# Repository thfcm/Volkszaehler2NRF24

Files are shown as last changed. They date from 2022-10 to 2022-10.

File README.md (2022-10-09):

# Volkszaehler2NRF24
A Battery powered Electric-Meter reader that sends data using nRF24 wireless.<br/>
This is based on the works of https://www.volkszaehler.org .
<br/>
<br/>
## Introduction
I started this project because I want to measure my power consumption during the day and see how my tiny 300pW Solar Power Plant fits in.
Fortunately, the electric-meter is a digital one with an IR interface for consumer-use that sends out a bunch or information like the counter reading or the current power reading.
As I live for rent and there is no power plug nearby my electric-meter, I was forced to build something that can last for a long time on a Battery.
<br/><br/>
The Receiver is in my cellar room next to the room with the power meters where my tiny home-server is running.
The far-end of this power-meter reader is directly connected to the home server via USB and sends the received data via a serial interface, so you can access it using Node-Red or anything else.

## Content
This project includes 

* [IRReader_Transmitter](https://github.com/thfcm/Volkszaehler2NRF24/tree/main/IRReader_Transmitter) - the IR Reader/Transmitter that you want to put on your energy-meter
* [Receiver](https://github.com/thfcm/Volkszaehler2NRF24/tree/main/Receiver) - the Receiver that receives the information and sends it to a Serial Port using USB
* [eMH Simulator](https://github.com/thfcm/Volkszaehler2NRF24/tree/main/eMH%20Simulator) - an eMH energy-meter simulator so you can test your hardware without standing next to your energy-meter with a laptop and strange devices in your hand that may  make neighbors asking strange questions

## Schematic:



## Hardware needed
<br/>
I build my prototype using hardware that I had lying around: 
- an IR diode that matches the wavelength of the NMH smart-meter by chance (needs to be determined but most IR diodes should work)
- an Arduino Board using a 328p microcontroller. We are going to run that one consuming as few power as possible. It does not matter if you are using the 16MHz/5V or the 8MHz/3.3V Version as we are going to modify that board to waste as few power as possible. In my case I was modifying an *Pro Micro board (16MHz/5V)* to run on 4MHz and 3.3V using an external power regulator.
- an nRF24 Transceiver. I was using an nRF24L01+ as I planned to use the 250kBaud transfer rate in the hope to use even less power with that. You should do fine with an nRF24L01 (without the "+"), too. In that case, you'll need to modify some settings as the non-plus transceivers do not support 250kBaud (they 'only' do 1MBaud or 2MBaud).
Your Receiver should match the capabilities.
- A Low-Dropout power regulator that has a small power consumption by its own. I am using HT7333 , but you can use any other regulatorthat fits, too. It even might be good to only use 3.0Volt or less (as long as it fits the needs of the 328p@4MHz and the nRF24). You can also stick with the one that is integrated on your board as long as it is a 3.3V regualtor as the nRF24-board will be destroyed if you run ith with 5V.
- a Sincle Cell (1S) LiPo Battery or something similiar. Make sure you use a Battery with a protection cirquit as I didn't integrated any protection. I am using a 18650 Battery with 2600mAh capacity and an integrated protection cirquit. Make sure the final discharging voltage is high enough so your voltage regulator can provide the minimum volate to your board as long as possible. You may even get rid of the power regulator if you can make sure that the end-of-charge voltage does not exceed the maximum rating of your nRF24 module.
<br/><br/>

## Hardware modification
<br/>
I removed the power LED as well as the power regulator that was mounted on the board. We do not need the LED. It only consumes power.
I also removed the integrated power regulator as it is not the most efficient one. It was replaced by the already mentioned external HT7333. You may do fine to keep the integrated one, depending on how less power you really want to waste.
I stabilized the 3.3V rail with a 220uF/10V condensator. That is optional but may help in case the nRF Module induces some peaks.
<br/>
<br/>

## Low Power
<br/>
When running something on battery, you usually want it to run as long as possible without replacing the battery.
I had the goal to have the reader running at least 6 month and ended up with more than 12 month (in theory - that needs to be confirmed).
<br/><br/>
To do so, I chose an Arduino compatible board that does not have a lot external peripheral attached. The Pro Mini I am using does not even have an USB port as the common USB-to-Serial chips use a lot of power even if you don't need them.
I also removed the power-LED as well as the integraded power regulator.
<br/><br/>
To save even more power, I have the Atmega328p running at 4MHz and using 3.3V. The less volts, the less power it is consuming. You can also run it with 3.0 Volts or even less to save even more power. 
I disabled all the internal peripheral devices the Atmega has and that we do not need (like ADC, Brown.out.Detection and so on).
<br/><br/>
I got that information from http://www.gammon.com.au/power so all the credits for that goes there.
<br/><br/>
In addition to that, the nRF24L01+ is set to a sleep mode as long as we don't have anything to send.
Also the Atmega328p is sleeping for most of its time. At the moment, it will sleep for 16 Seconds, wakes up, waits for some Serial Data from the IR port and extracts the data we want. It then sends those 8 Bytes and goes back to sleep again immediantly.
<br/><br/>

## Range

You might want to know the range of that system. But range depends on so many factors, you can not really tell anything. You should test it under the conditions you have.
To extend the range a little bot, you can raise the transmit power, add some shielding to the receiver to block noise of have a look at [https://www.instructables.com/Enhanced-NRF24L01/](https://www.instructables.com/Enhanced-NRF24L01/).

## Used external Libraries
<br/>
For that project we are using the following libraries:

* [RF24 Library from https://nrf24.github.io/RF24/](https://nrf24.github.io/RF24/)

* [AltSoftSerial from https://www.pjrc.com/teensy/td_libs_AltSoftSerial.html](https://www.pjrc.com/teensy/td_libs_AltSoftSerial.html) as the regular SoftwareSerial was too slow

* [SML Parser from https://github.com/olliiiver/sml_parser](https://github.com/olliiiver/sml_parser) to parse the SML Data the electric-meter sends

<br/><br/>
## Example Images







## Discord Server
I have opened a Discord Server so you can ask questions and exchange information.
Please note that I have a real live, too. So I might not be able to answear within minutes or at all.

https://discord.gg/fCE7YD76QE

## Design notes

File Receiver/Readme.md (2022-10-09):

# Receiver
This is the Receiver of this project.

It will send the data received via the nRF24l01+ Module to a Computer using Serial (via USB).
This might be your Node-Red-Server RaspberryPi or anything else.

You can run this code either on a Wemos D1 Mini (compatible with many ESP8266 based Boards) or a Arduino Nano V3 (compatible with most Atmega 328p-based boards).
It is easy to adapt this code for any other board, too.



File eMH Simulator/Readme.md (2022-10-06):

## eMH Simulator

This little piece of code will simulate an eMH energy-meter and will send simulated data using an IR Diode.
This way you can test your Volkszaehler2NRF24 on your desk until everything works.
<br/>
This sketch uses a binary file from the [libsml library from https://github.com/olliiiver/sml_parser](https://github.com/olliiiver/sml_parser) that contains a telegram similar to an eMH meter will send out.
Note, that at least the Address of the *current power* might differ from the Address your energy-meter might use (I had that in my case).
<br/>                        
I used a Teensy 3.1 Board that I had laying around but any other board should work fine, too.
In case you are going to use another board, you might have to replace Hardware-Serial 1 with a Software-Serial.
This is, because the Teensy is cabable of more than one Serial Interface that is mapped in hardware.
In case the board you are using does not have more than one Hardware Serial interface, you can use SoftwareSerial instead.

(I know this is confusing and I will change code to use SoftwareSerial in the future so you do not have to change this point in code for yourself)

<br/>                                 
Simply solder an IR TX Diode between 3.3V and your TX Pin. Depending on the Diode you are using, you should install the matching current limiting resistor.

Example:<br/>

<br/><br/>
You can check if the Simulator is sending data using your Smartphones Camera. <br/>
Most of them are capable of "seeing" infrared light (which looks like a purple pale light):<br/>


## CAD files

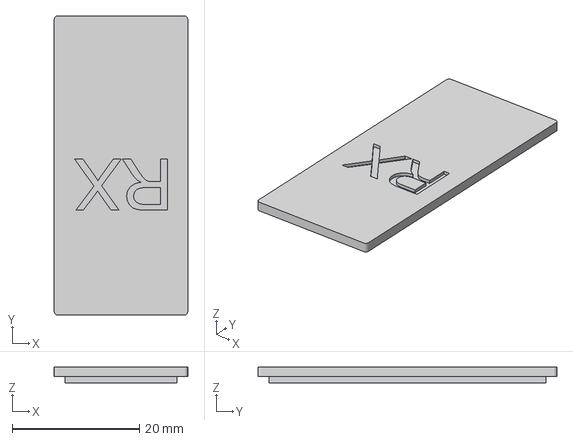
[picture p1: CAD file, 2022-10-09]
Receiver/3DprintCases/NanoProCase/lid.3mf
21.0 x 47.0 x 2.50 mm

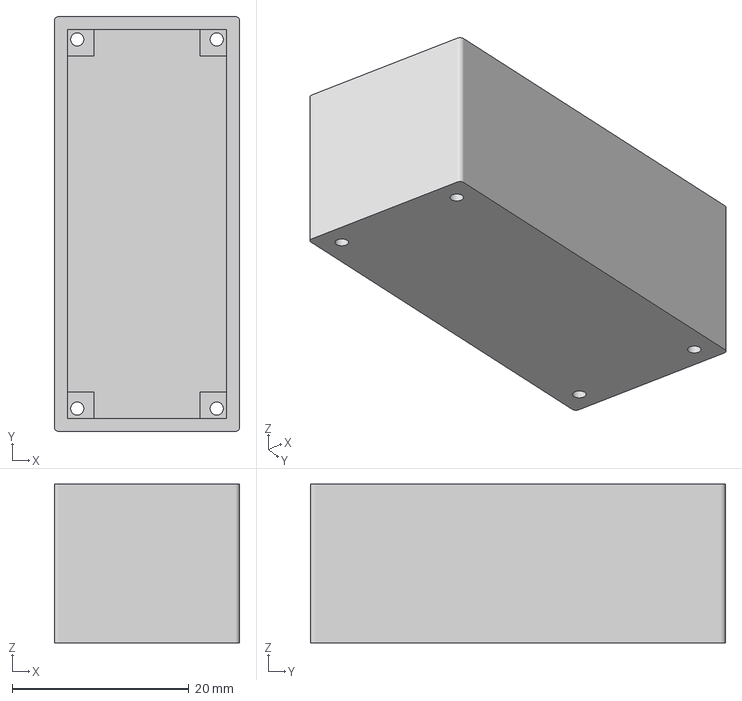
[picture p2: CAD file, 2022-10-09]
Receiver/3DprintCases/NanoProCase/case.3mf
21.0 x 47.0 x 18.0 mm

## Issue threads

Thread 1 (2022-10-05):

feed-in power from your solar power plant causes wrong values

thfcm, 2022-10-05:
In case your solar power plant produces more energy than your home consumes, the energy-meter will transmit a value that should cover the feed-in power - but somewhere we do not cover that yet wich causes an very high consumption value.

A work-arount is to set all values above a certain Value (lets say 30kW) to 0 ( I am doing that in node-red at the moment) but we should  fix the root of that problem.

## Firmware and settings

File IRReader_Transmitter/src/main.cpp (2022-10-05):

#include <Arduino.h>
#include <main.h>
#include <AltSoftSerial.h>
#include "sml.h"
#include <avr/power.h>
#include <avr/sleep.h>
#include <avr/wdt.h>
#include <SPI.h>
#include <nRF24L01.h>
#include <RF24.h>





RF24 radio(CE_PIN, CSN_PIN);                // Create a Radio
AltSoftSerial mySerial;                     // Create a SoftwareSerial Instance
sml_states_t currentState;

unsigned long wake_up_timestamp           = 0;
unsigned int iHandler                     = 0;
#ifdef USE_SERIAL_DEBUG 
const char msgTextBegin[] PROGMEM         = "Begin ";
#endif
double CPwr = -2, SumWh = -2;
byte dataToSend[10]                       = {0x0A,0xFF,0x0E,0x00,0x00,0x00,0x00,0x00,0x00,0xFF} ;   //Buffer will hold 2x double (4Byte) and 2x 1Byte additional info. Increase, if double uses more Bytes
const byte slaveAddress[5]                = {'R','x','A','A','A'};


/* ####################################################################################### *
 *
 * 
 * ####################################################################################### */


typedef struct {
  const unsigned char OBIS[6];
  void (*Handler)();
} OBISHandler;



void PowerSum() {
  smlOBISWh(SumWh);
}


void CurrentPower() {
  smlOBISW(CPwr);
}


// clang-format off
OBISHandler OBISHandlers[] = {
  {{ 0x01, 0x00, /*0x0f*/ 0x10, 0x07, 0x00, 0xff }, &CurrentPower},      //  1-0:1.8.0*255  Bezug Total
  {{ 0x01, 0x00, 0x01, 0x08, 0x00, 0xff }, &PowerSum},                  //  1-0:15.7.0*255 Aktueller Bezug
  {{ 0, 0 }}
};
// clang-format on


/**
 * @brief Set the Power Save Options object
 * 
 */
void setPowerSaveOptions() {
  MCUCR = bit (BODS) | bit (BODSE);         // turn on brown-out enable select
  MCUCR = bit (BODS);                       // this must be done within 4 clock cycles of above
  ADCSRA = 0;                               // disable ADC
  power_adc_disable();                      // disable ADC
  power_twi_disable();                      // disable TWI (I2C)
  power_timer2_disable();
  power_timer2_disable();
  //power_timer1_disable();                 //AltSoftSerial nutzt Timer1
}


// watchdog interrupt
ISR (WDT_vect) {
   wdt_disable();  // disable watchdog
}  // end of WDT_vect


/**
 * @brief Send the CPU to a Sleep state for 8 seconds
 * 
 */
void sendCPUtoSleep() {
    // clear various "reset" flags
    MCUSR = 0;     
    // allow changes, disable reset
    WDTCSR = bit (WDCE) | bit (WDE);
    // set interrupt mode and an interval 
    WDTCSR = bit (WDIE) | bit (WDP3) | bit (WDP0);    // set WDIE, and 8 seconds delay
    wdt_reset();  // pat the dog
  
    set_sleep_mode (SLEEP_MODE_PWR_DOWN);  
    noInterrupts ();           // timed sequence follows
    sleep_enable();

    // turn off brown-out enable in software
    MCUCR = bit (BODS) | bit (BODSE);
    MCUCR = bit (BODS); 
    interrupts ();             // guarantees next instruction executed
    sleep_cpu ();  
  
    // cancel sleep as a precaution
    sleep_disable();
}


void sleep16(){
    #ifdef USE_SERIAL_DEBUG 
      Serial.println("sleeping");
    #endif
    delay(100);
    sendCPUtoSleep();         //Send CPU to sleep for 8 Seconds
    delay(100);               //needs some delay inbetween or it won't sleep a second time
    sendCPUtoSleep();         //Send CPU to sleep for 8 Seconds
    #ifdef USE_SERIAL_DEBUG 
      Serial.println("\n\nwoke up");
    #endif
    setPowerSaveOptions();
    wake_up_timestamp=millis();   
}


void setup() {
  if(F_CPU == 8000000) clock_prescale_set(clock_div_2);
  if(F_CPU == 4000000) clock_prescale_set(clock_div_4);


  setPowerSaveOptions();

#ifdef USE_SERIAL_DEBUG 
  Serial.begin(HW_SERIAL_BAUD);
  Serial.print((__FlashStringHelper*)msgTextBegin);
  Serial.print(F_CPU/1000000);
  Serial.println("MHz");
#endif
  pinMode(5, INPUT_PULLUP);           //ToDo: Entferne mich nach dem Umbau

  radio.begin();
  radio.setDataRate(NRF24_DATA_RATE);
  radio.setChannel(NRF24_CHANNEL);

  radio.setRetries(NRF24_RETRY_DELAY, NRF24_RETRY_COUNT); // delay, count
  radio.openWritingPipe(slaveAddress);

  

  //Software-Serial 1 : lesen aus dem IR-Sensor
  mySerial.begin(SW_SERIAL_BAUD);
  mySerial.listen();

  bool rslt;
  rslt = radio.write( &dataToSend, sizeof(dataToSend) );     //Send Dummy Data on Startup (mostly for debug purposes but also useful to count restarts)
  radio.powerDown(); 
#ifdef USE_SERIAL_DEBUG
  Serial.print("Sending Dummy ...");
  if(rslt)Serial.println("success");
  else Serial.println("failed");
#endif

  
}


/**
 * @brief Sendet die Daten aus dem Buffer
 * Hierzu wird das nRF Modul kurz eingeschaltet und dann wieder in den Standby geschickt
 */
void sendData(double currentPower, double accumulatedPower) {
  radio.powerUp();
  bool rslt;
  int pos = 0;
  byte * valuePtr = (byte *) &currentPower;                 //we find the address of the first byte
  for(unsigned int i=0; i<sizeof(double); i++){
    dataToSend[pos]=*(valuePtr + i);                      //copy data byte-wise to the array starting at 0
    pos++;
  }

  valuePtr = (byte *) &accumulatedPower;                    //we find the address of the first byte
  for(unsigned int i=0;i<sizeof(double); i++){
    dataToSend[pos]=*(valuePtr + i);                      //copy data byte-wise to the array starting at the end of the data copied above
    pos++;
  }

  //dataToSend[pos++] = 0x80;                                 //Dummy Data for later use (e.g. battery status)
  //dataToSend[pos] = 0xFF;                                 //Dummy Data for later use (e.g. system status)


  rslt = radio.write( &dataToSend, sizeof(dataToSend) );
      // Always use sizeof() as it gives the size as the number of bytes.
      // For example if dataToSend was an int sizeof() would correctly return 2

#ifdef USE_SERIAL_DEBUG 
  Serial.print("Data Send: ( ");
  for(unsigned int i=0;i<sizeof(dataToSend);i++) {
    if((byte)dataToSend[i]<0x10) Serial.print('0');
    Serial.print((byte)dataToSend[i], HEX);
    Serial.print(' ');
  }
  Serial.println(")");
  if (rslt) {
      Serial.println("Ack received");
  } else {
      Serial.println("TXS failed");
  }
#endif
  radio.powerDown();
}

/**
 * @brief put a Byte into the SML library
 * 
 * @param currentChar 
 */
void smlReadByte(unsigned char currentChar) {
  currentState = smlState(currentChar);
  if (currentState == SML_START) {
    /* reset local vars */
    CPwr = -3;
    SumWh = -3;
  }

  if (currentState == SML_LISTEND) {
        /* check handlers on last received list */
        for (iHandler = 0; OBISHandlers[iHandler].Handler != 0 &&
                           !(smlOBISCheck(OBISHandlers[iHandler].OBIS));
             iHandler++)
          ;
        if (OBISHandlers[iHandler].Handler != 0) {
          OBISHandlers[iHandler].Handler();
        }
  }


  if (currentState == SML_FINAL) {
        sendData(CPwr, SumWh);
        #ifdef USE_SERIAL_DEBUG 
          Serial.print(F("\n\n"));
          Serial.print(F("CP: "));
          Serial.println(CPwr, DEC);
          Serial.print(F("ZS: "));
          Serial.println(SumWh, DEC);
          Serial.println("S2");
        #endif
        delay(10);
        sleep16();
      }
}


/**
 * @brief Main Loop
 * 
 */
void loop() {
  if(mySerial.available()>0) {
    while(mySerial.available()>0) {
      //byte b = mySerial.read();
      //if(b<0x10)Serial.print('0');
      //Serial.print(b,HEX);
      //Serial.print(' ');
      //smlReadByte(b);
      smlReadByte(mySerial.read());
    }
  }


  /*
  Wurde kein Paket empfangen und/oder ist die Wartezeit abgelaufen, dann schicke die CPU in den Sleep-Mode.
  Der Sleep-Mode wird auch aufgerufen, wenn das Paket vollständig empfangen und ausgewertet wurde.
  */
  if(millis()>wake_up_timestamp+WAKE_WAIT_TIME) {
    #ifdef USE_SERIAL_DEBUG 
      Serial.println("\nS1"); delay(10);
    #endif
    sleep16();
  }
}

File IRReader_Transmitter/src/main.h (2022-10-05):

#define HW_SERIAL_BAUD 19200                //Baud-Rate für die Hardware-Serielle Schnittstelle (Debug Monitor)
#define SW_SERIAL_BAUD 9600                 //Baud-Rate f+r den IR Lesekopf
#define WAKE_WAIT_TIME 5000                 //Wir warten 5000ms auf ein Datagramm über die IT-Schnittstelle und gehen danach wieder schlafen

#define CE_PIN   9
#define CSN_PIN 10
#define NRF24_CHANNEL         100           // 0 ... 125
#define NRF24_DATA_RATE       RF24_250KBPS  // RF24_2MBPS, RF24_1MBPS, RF24_250KBPS
#define NRF24_RETRY_DELAY     2             // Delay bewteen retries, 1..15.  Multiples of 250µs.
#define NRF24_RETRY_COUNT     2             // Number of retries, 1..15.

#define USE_SERIAL_DEBUG

void PowerSum();                                            //Callback to extract the accumulated power from the SML Data
void CurrentPower();                                        //Callback to extract the current power from the SML Data
void setPowerSaveOptions();                                 //sets all Power-Safe-Options for the Microcontroller
void sendCPUtoSleep();                                      //sends the CPU to sleep for 8 Seconds
void sleep16();                                             //sends the CPU to Sleep for 16Seconds (uses sendCPUtoSleep)
void setup();
void loop();
void sendData(double currentPower, double accumulatedPower);//send Data using the nRF24 Modem
void smlReadByte(unsigned char currentChar);                //add a byte to the SML Parser

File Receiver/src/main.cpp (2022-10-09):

#include <Arduino.h>
#include <SPI.h>
#include <nRF24L01.h>
#include <RF24.h>

union u_tag {
    byte b[4];
    float fval;
} u;


// default pinout
#ifdef ESP8266
  #define DEF_RF24_CS_PIN         15      //D8
  #define DEF_RF24_CE_PIN         2       //D4
  #define DEF_RF24_IRQ_PIN        //0     //D3
#endif

#ifdef NANOPRO
  #define DEF_RF24_CS_PIN         A1
  #define DEF_RF24_CE_PIN         A0
  #define DEF_RF24_IRQ_PIN        3 //can only be 2 or 3 on a 328-Based Controller
#endif

#define NRF24_CHANNEL         100           // 0 ... 125
#define NRF24_DATA_RATE       RF24_250KBPS  // RF24_2MBPS, RF24_1MBPS, RF24_250KBPS
boolean data_received = false;

RF24 radio(DEF_RF24_CE_PIN, DEF_RF24_CS_PIN); // Create a Radio

const byte thisSlaveAddress[5] = {'R','x','A','A','A'};
char dataReceived[8]; // this must match dataToSend in the TX

//==============

void getData() {
  float currentPower = 0;
  float powerReceived = 0;
    if ( radio.available() ) {
      while(radio.available()) {
          radio.read(&dataReceived,sizeof(dataReceived));
          for(int i = 0 ; i< 4; i++){
            u.b[i] = dataReceived[i];
          }
          currentPower=u.fval;

          for(int i = 0 ; i<4; i++){
            u.b[i] = dataReceived[i+4];
          }
          powerReceived=u.fval;
          Serial.print("Z:"); Serial.println(powerReceived/1000);
          Serial.print("P:"); Serial.println(currentPower);
      }
    }
    radio.flush_rx();
    data_received=false;    //reset flag
}

void interruptHandler() {
  delayMicroseconds(250);                         // wait until the transition process has settled 
  bool tx_ok, tx_fail, rx_ready;                  // declare variables for IRQ masks
  radio.whatHappened(tx_ok, tx_fail, rx_ready);   // get values for IRQ masks
  if(rx_ready){
    data_received=true;                           //set flag to TRUE so we can handle received data - do not do heavy operations within an intrrupt routine
  }
}  // interruptHandler


void setup() {
  Serial.begin(115200);

  while(!Serial) {};
  Serial.println("RX Begin");
  pinMode(DEF_RF24_IRQ_PIN, INPUT);
  attachInterrupt(digitalPinToInterrupt(DEF_RF24_IRQ_PIN), interruptHandler, FALLING);

  radio.begin();
  radio.setDataRate(NRF24_DATA_RATE);
  radio.setChannel(NRF24_CHANNEL);
  radio.openReadingPipe(1, thisSlaveAddress);
  radio.maskIRQ(1, 1, 0);    //tell the nRF Module ro raise interrupt when Data is received
  radio.startListening();
  
  
  /*Serial.println("RX Init Done");
  Serial.print("RX Address:");
  for(int i = 0 ; i<sizeof(thisSlaveAddress); i++) {
    if(thisSlaveAddress[i]<0x10) Serial.print('0');
    Serial.print(thisSlaveAddress[i], HEX);
    Serial.print(' ');
  }
  Serial.println();
  Serial.print("CRC Length:");
  Serial.println(radio.getCRCLength(),DEC);*/
}

void loop() {
    if(data_received) {
      getData();
    }
}
